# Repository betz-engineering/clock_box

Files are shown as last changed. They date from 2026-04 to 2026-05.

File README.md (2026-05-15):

# clock_box
KiCad PCB design for the clock_box: A low cost, versatile signal generator for usage in the digital electronics lab.

See also [clock_box description](https://betz-engineering.ch/open_hardware/clock_box/).

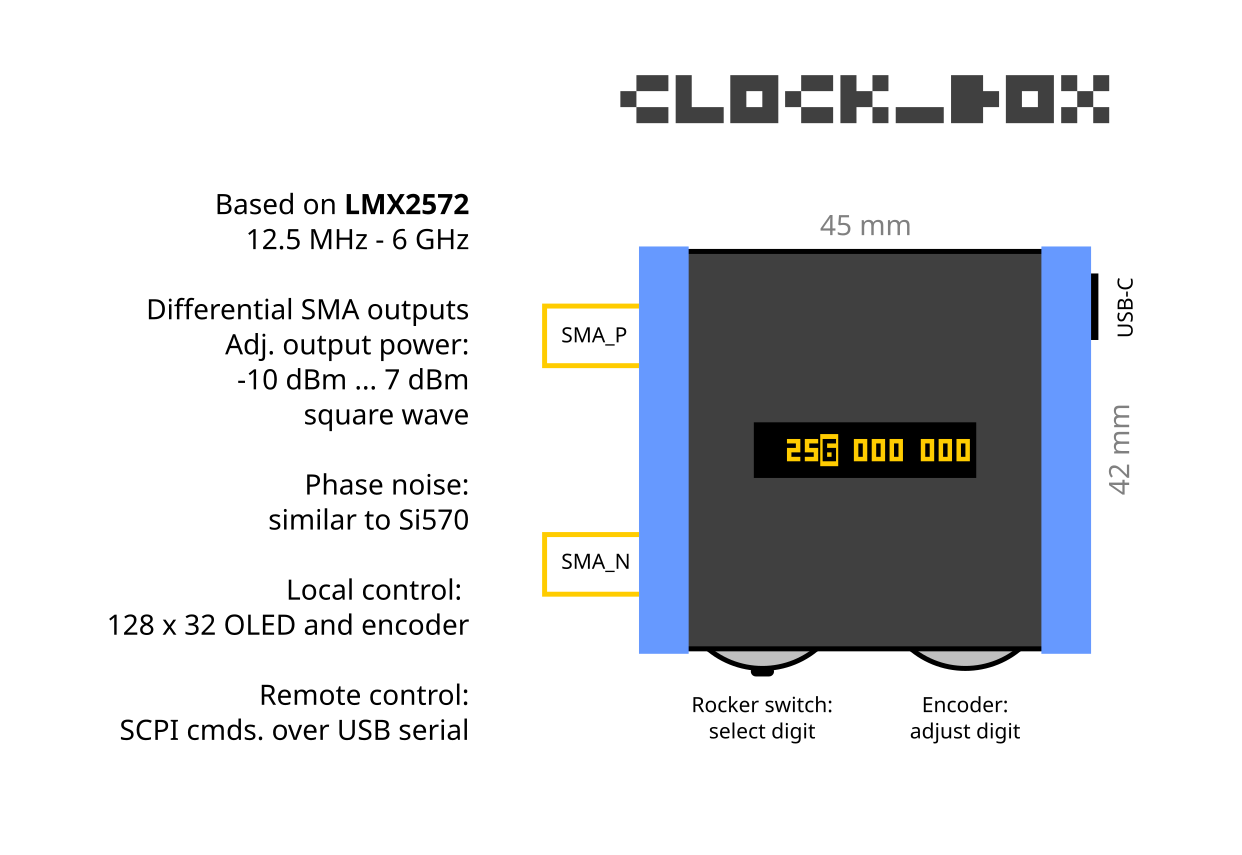
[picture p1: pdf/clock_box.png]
clock_box concept


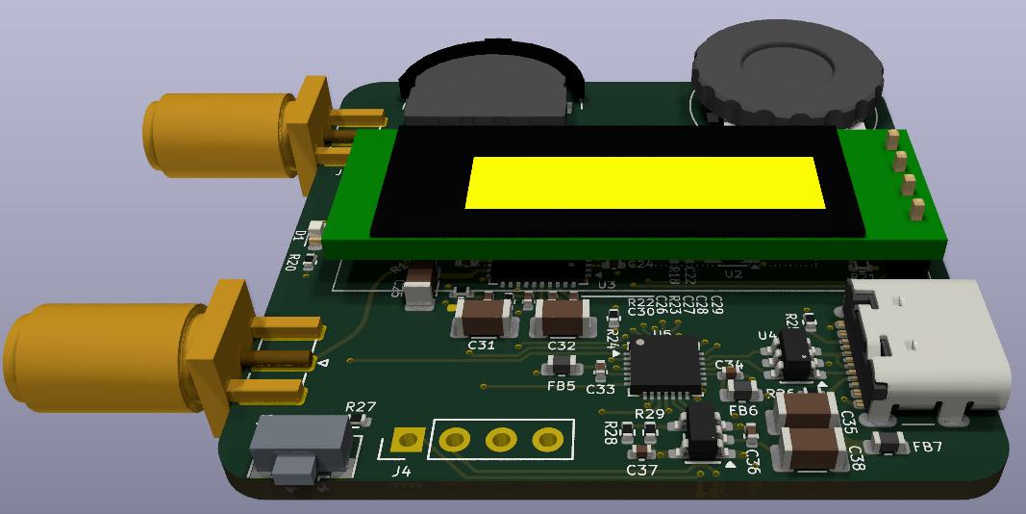
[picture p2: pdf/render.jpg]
clock_box render


[Schematic](pdf/clock_box.pdf)

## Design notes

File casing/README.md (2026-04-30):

# 3D printed casing for clock_box

The casing consists of a top and bottom shell which fits tightly around the clock_box PCB.

To hold the shells together, the following hardware is needed:

  * 2x M2 Hex Socket screws of length 6 mm
  * 2x M2 Nuts of thickness 1.6 mm

It was modeled in [Openscad](https://openscad.org/) version `2024.06.04.ai19515`.

The dimensions have been optimized to print well on a Bambulab A1 using PLA filament.

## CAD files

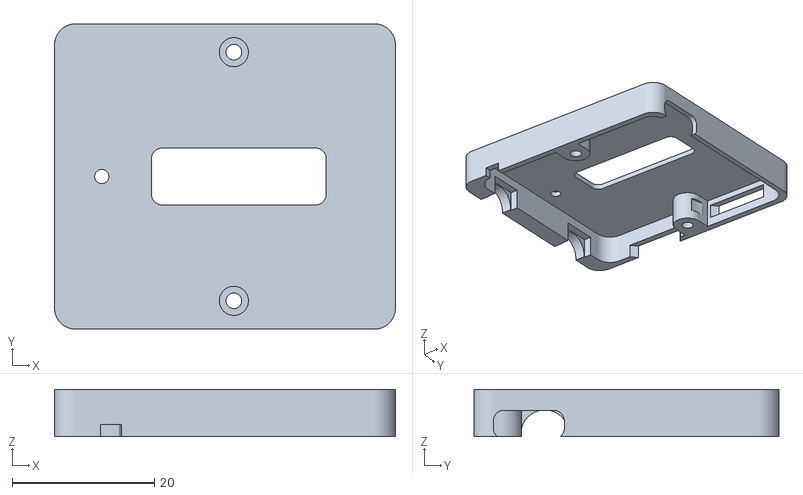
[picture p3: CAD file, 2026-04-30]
casing/casing_top.stl
48.0 x 43.0 x 6.65

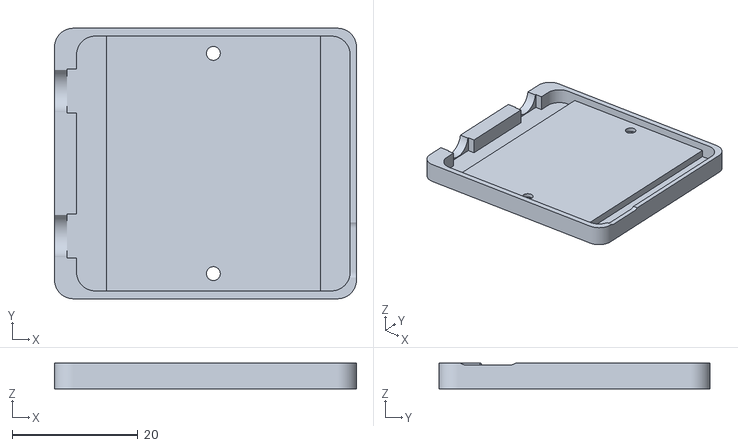
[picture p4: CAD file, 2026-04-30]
casing/casing_bottom.stl
48.0 x 43.0 x 4.10

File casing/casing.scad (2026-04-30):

$fn = $preview ? 30 : 150;

include <OLED_0.91.scad>

// Makes the casing thickness assymetric in y-direction
left_shift = 2.5 / 2;

w_shell = 1.5;
// o_x = 48;
o_x = 46.5;
o_y = 43;
o_z = 10.75;

// centered on XY only
module roundedcubez_(size = [1, 1, 1], radius = 0.5) {
	linear_extrude(height=size[2]) {
		square([size[0] - 2 * radius, size[1]], center=true);
		square([size[0], size[1] - 2 * radius], center=true);
		for (i=[-1, 1])
			for (j=[-1, 1])
				translate([i * (size[0] / 2 - radius), j * (size[1] / 2 - radius), 0])
					circle(r = radius);
	}
}

module enclosure() {
	difference() {
		translate([-left_shift, 0, -4.5]) {
			roundedcubez_(size=[o_x + 4 - left_shift * 2, o_y, o_z], radius=3);
			// translate([0, -o_y / 2, 0])
			// 	cube(size=[(o_x + 4 - left_shift * 2) / 2, o_y / 2, o_z]);
		}

		// Hollow it out
		translate([0, 0, -3.5])
			roundedcubez_(size=[o_x - w_shell * 2, 40.5, o_z - 2], radius=3);

		// OLED
		// translate([1.96, 0, 0])
		// 	roundedcubez_(size=[23, 7, 10], radius=1.5);
		translate([0.7, 0, 0])
			roundedcubez_(size=[23 + 1.6, 7 + 1, 10], radius=1.5);

		// USB
		translate([o_x / 2 - 7, -13.75, 1.3])
			rotate([90, 0, 90])
				roundedcubez_(size=[10, 4, 10], radius=1.5);
		// translate([27.75, -11.5 - 5, -7])
		// 	roundedcubez_(size=[10, 15 + 10, 15], radius=4);


		// SMA
		for (i=[-1, 1])
			translate([-o_x / 2, 11.5 * i, 0])
				rotate([90, 0, 90]) {
					cylinder(h=10, d=6.7, center=true);
					translate([0, 0, 2.5])
						cube([7, 7, 5], center=true);
				}

		// Power LED
		translate([-18.6, 0, o_z - 7.5])
			cylinder(d=2, h=5);
	}

	// bottom plate
	translate([0, 0, -3])
		cube(size=[34, o_y - w_shell, 2], center=true);
}


module enclosure2(is_top=false) {
	intersection() {
		difference() {
			union() {
				enclosure();
				if (is_top) {
					// Standoffs
					for (i=[-1, 1]) {
						translate([0, i * 17.5, -0.5]) {
							cylinder(h=o_z - 5, d=5.5, center=false);
							translate([-5.5 / 2, 2 * i - 2, 0])
								cube([5.5, 4, o_z - 5], center=false);
						}
					}
				}
			}
			if (is_top) {
				// Encoder
				translate([10, 16, 2.7])
					cylinder(h=2.7, d=15.5, center=true);
				// translate([17.3, 16, 2.6])
				// 	cylinder(h=2.5, d=16, center=true);

				// Rocker
				translate([-10, 16, 0.9 - 2])
					cylinder(h=2.5 + 4, d=15, center=true);

				// BOOT0 switch
				translate([-17.3, -20, 0.55 - 2])
					cube(size=[3, 10, 1.5 + 4], center=true);
			}
			for (i=[-1, 1]) {
				// M2 screw-holes
				translate([0, i * 17.5, 0])
					cylinder(h=20, d=2.2, center=true);
				// M2 hex nut holes
				translate([0, i * 17.5, -6.5 + 1.7])
					cylinder(h=4, d=4.2 * 1.155, center=true, $fn=6);
				// Screw head holes
				translate([0, i * 17.5, 10.5 - 3.75])
					cylinder(h=10, d=4.1, center=true);
			}
		}
		split_offset = -0.4;
		translate([0, 0, is_top ? 50 + split_offset : -50 + split_offset])
			cube(size=[100, 100, 100], center=true);
	}
}

// Mock components for Preview

// module screw(l=6) {
// 	cylinder(h=2, d=3.8);
// 	translate([0, 0, 2])
// 		cylinder(h=l, d=2.0);
// }

// translate([0, 17.5, 3.75])
// 	rotate([180, 0, 0])
// 		screw();

// PCB mockup: Needs a 3D export in .stl format from Kicad
// module pcb() {
// 	color("yellow")
// 		translate([0, 0, -2])
// 			import("clock_box.stl");
// 	translate([1, 0.78, 1.9])
// 		rotate([0, 0, 180])
// 			oled();
// }


// Export the 2 shells
intersection() {
	union() {
		enclosure2(true);
		// enclosure2(false);
	}
	// Cross-section view
	// translate([50, 0, 0])
	// 	cube(size=[100, 100, 100], center=true);
}

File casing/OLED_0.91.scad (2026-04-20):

module oled() {
	color("green")
		translate([0, 0, 1.2 / 2])
			cube(size=[38, 12, 1.2], center=true);

	color("black")
		translate([2, 0, 1.2 + 1.15 / 2])
			cube(size=[30, 11.5, 1.15], center=true);

	color("yellow")
		translate([1-0.71, 0.78, 1.2 + 1.15 + 0.5 / 2])
			cube(size=[22.38, 5.58, 0.5], center=true);

	for(i=[0:3])
		translate([-19 + 1.25, (i - 1.5) * 2.54, -1.75]) {
			cube(size=[0.6, 0.6, 7], center=true);
			color("black")
				translate([0, 0, 0.6])
					cube(size=[2.5, 2.5, 2.3], center=true);
		}
}

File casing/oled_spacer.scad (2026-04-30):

// the most complex CAD model you've ever seen!
cube(size=[10, 2.5, 2.5]);

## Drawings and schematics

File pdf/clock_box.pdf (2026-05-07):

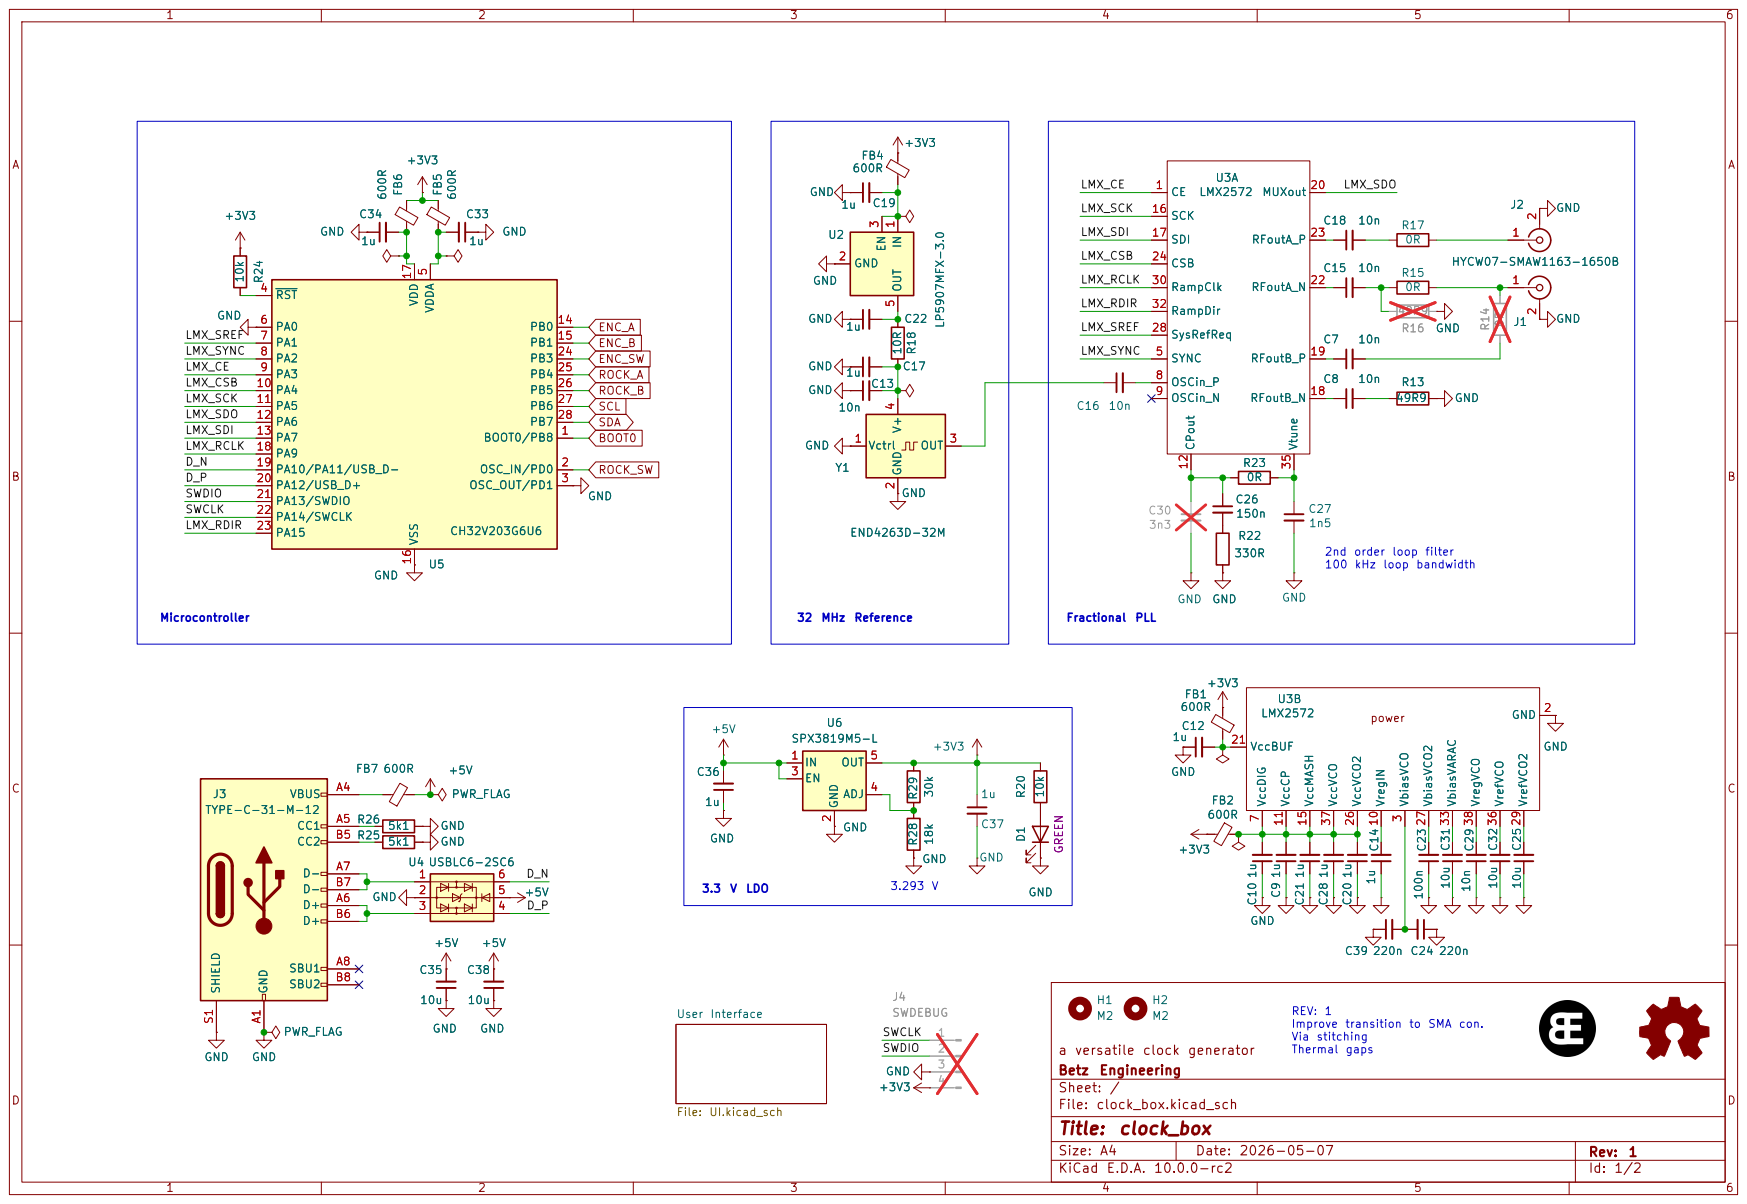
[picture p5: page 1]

Improve transition to SMA con. Via stitching

Size: A4 | Rev: 1

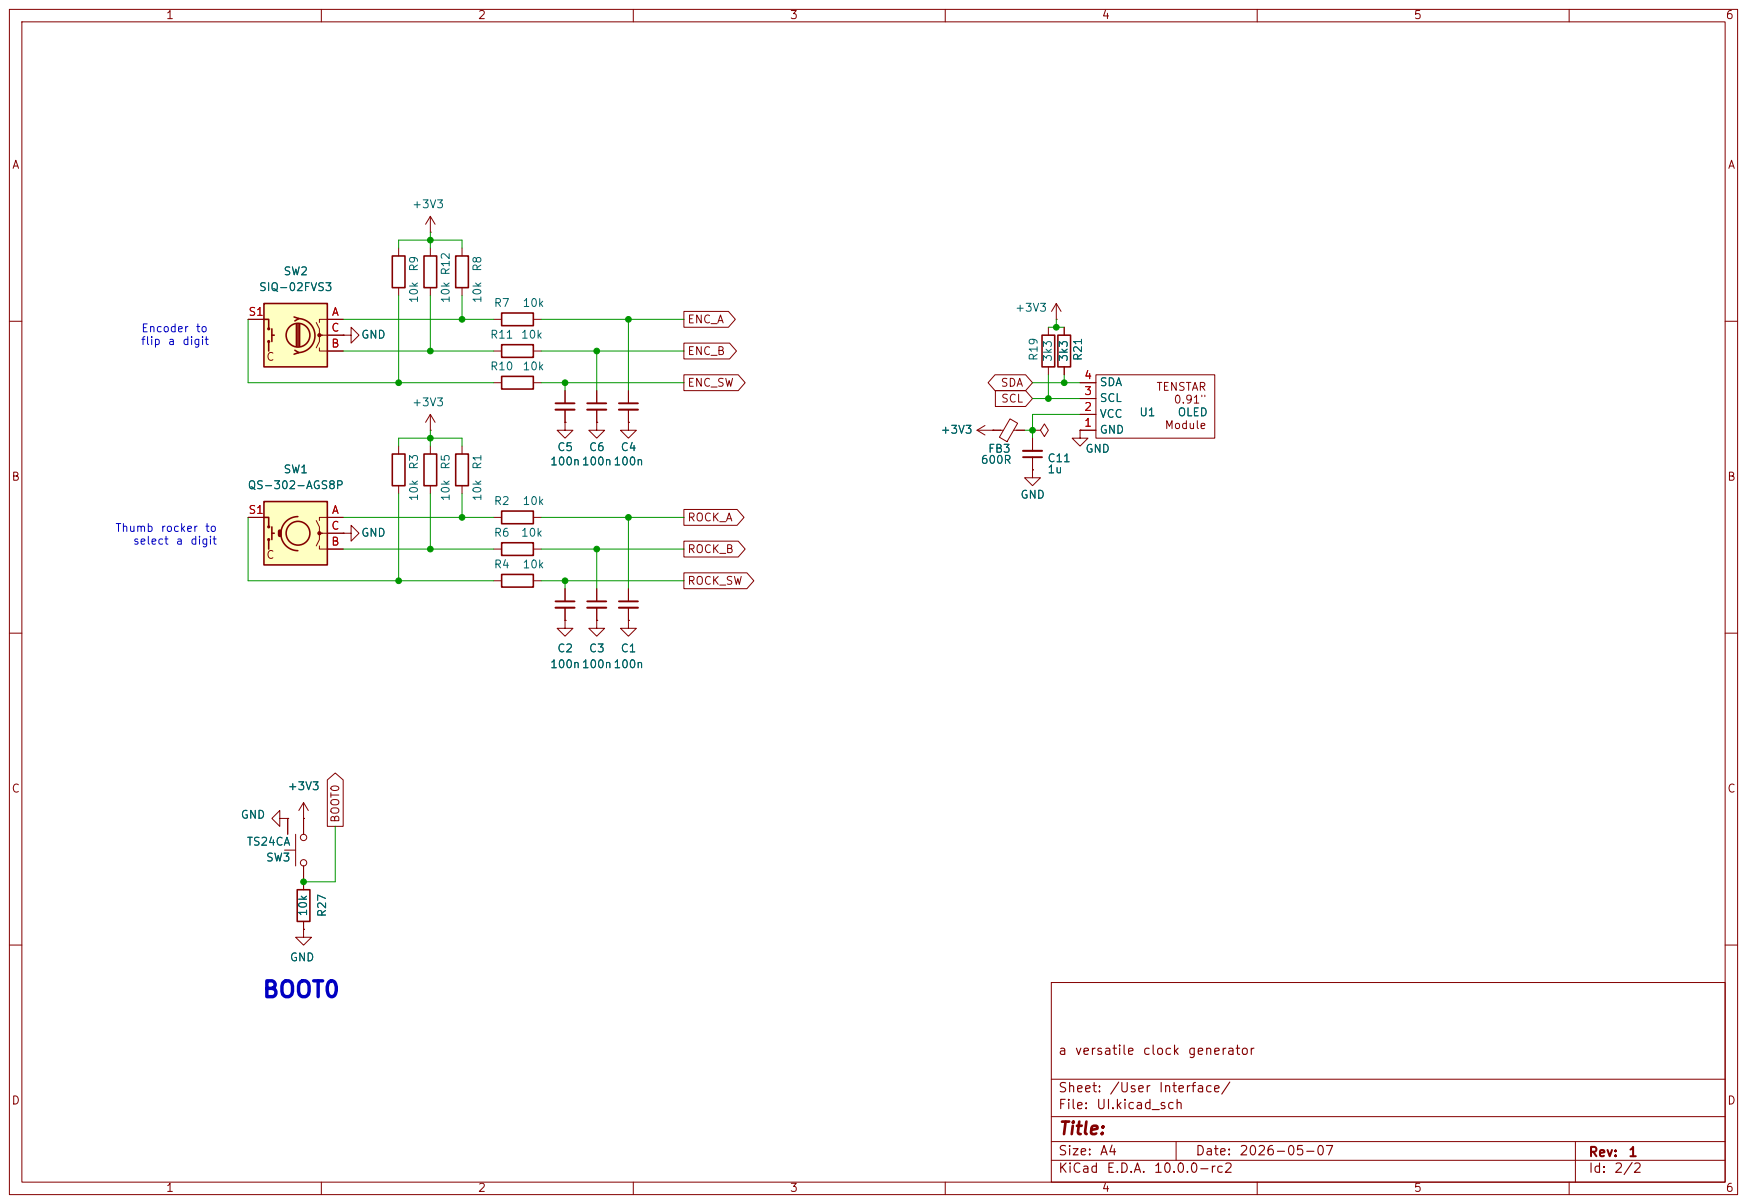
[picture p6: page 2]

Size: A4 | Rev: 1

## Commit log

2026-03-29 initial commit
    everything is work in progress.
    Component choice and Schematic more or less complete.
    Artwork in placement-exploration stage. PCB size not determined yet.
    [clock_box.kicad_pcb, clock_box.kicad_sch]
2026-03-31 add .step for the encoder
    [clock_box.kicad_pcb]
2026-03-31 placement of the Si570 version looks good
    [clock_box.kicad_pcb, clock_box.kicad_sch]
2026-04-01 add LMX2572 symbol
    [UI.kicad_sch, clock_box.kicad_pcb, clock_box.kicad_sch]
2026-04-01 add TCXO
    [UI.kicad_sch, clock_box.kicad_pcb, clock_box.kicad_sch]
2026-04-01 add loop filter and support components
    [UI.kicad_sch, clock_box.kicad_pcb, clock_box.kicad_sch]
2026-04-02 loop filter: increase to max. possible bandwidth.
    [clock_box.kicad_sch]
2026-04-02 upgrade to Kicad 10
    [UI.kicad_sch, clock_box.kicad_pcb, clock_box.kicad_sch]
2026-04-02 component placement completed
    [clock_box.kicad_pcb, clock_box.kicad_sch]
2026-04-03 add concept picture
    [clock_box.kicad_pcb]
2026-04-03 Clean up schematic
    [clock_box.kicad_sch]
2026-04-03 add BOOT0 button. Routing progress.
    [UI.kicad_sch, clock_box.kicad_pcb, clock_box.kicad_sch]
2026-04-04 routing completed
    [UI.kicad_sch, clock_box.kicad_pcb, clock_box.kicad_sch]
2026-04-04 fix ERCs, add power supply to LMX
    [UI.kicad_sch, clock_box.kicad_sch]
2026-04-04 layout finished, 0 DRC errors, 3 warnings
    [clock_box.kicad_pcb, clock_box.kicad_sch]
2026-04-04 geographical re-annotate
    [clock_box.kicad_pcb]
2026-04-04 fix up silkscreen
    [UI.kicad_sch, clock_box.kicad_pcb, clock_box.kicad_sch]
2026-04-05 add 3D model of the rocker switch
    [clock_box.kicad_pcb]
2026-04-05 add _all_ 3D models
    [clock_box.kicad_pcb]
2026-04-05 add split casing
    [clock_box.kicad_pcb]
2026-04-06 switch to QS-302 thumb switch, much smaller
    move the LDO up from the bottom to the middle
    finish the 3D printed casing
    [UI.kicad_sch, clock_box.kicad_pcb]
2026-04-08 optimize BOM
    [UI.kicad_sch, clock_box.kicad_pcb, clock_box.kicad_sch]
2026-04-08 add 2x M2 mounting holes to the PCB and casing
    [clock_box.kicad_pcb]
2026-04-08 improve casing
    [UI.kicad_sch, clock_box.kicad_pcb, clock_box.kicad_sch]
2026-04-08 final touches on the silkscreen
    [clock_box.kicad_pcb]
2026-04-08 put the mounting holes back
    [clock_box.kicad_pcb, clock_box.kicad_sch]
2026-04-20 increase clearance to oled by 1 mm.
    Make o_z parameteric to define the overall casing (and inside cavity) height
2026-04-20 casing: make display cut-out bigger. Second test print.
2026-04-20 set the screws deeper (so they can catch the nut more easily)
    start investigating the display cut-out problem
2026-04-20 increase height of encoder slot
2026-04-20 casing: fix the hole for the power LED
2026-04-21 RF traces: via stitching and better transition to SMA-con. pads
    [clock_box.kicad_pcb, clock_box.kicad_sch]
2026-04-30 add casing directory
    [OLED_0.91.scad, casing.scad, casing_bottom.stl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]
2026-05-07 Rev: 1, add thermals to headers
    also in Rev: 1
    * via stitching on RF traces
    * better impedance match to SMA con pad
    [UI.kicad_sch, clock_box.kicad_pcb, clock_box.kicad_sch]
